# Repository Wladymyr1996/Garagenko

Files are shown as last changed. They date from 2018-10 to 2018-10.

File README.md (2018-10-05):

# Garagenko
Garagenko is a project of remote controller for garage door or gate.<br><br>
You can set youre language in Garagenko.ino, in define option LANG. You must wite code of youre language.<br>
Now you can set next languages:<br>
* Ukrainian     0
* English       1
* Russian       2

Ви можете встановити Вашу мову у файлі Garagenko.ino в LANG встановіть код Вашої мови.<br>
Наразі доступні коди:<br>
* Українська    0
* Англійська    1
* Російська     2

Вы можете использовать Ваш язык в файле Garagenko.ino в LANG утсановите код Вашего языка.<br>
Сейчас доступны коды:
* Украинский    0
* Английский    1
* Русский       2

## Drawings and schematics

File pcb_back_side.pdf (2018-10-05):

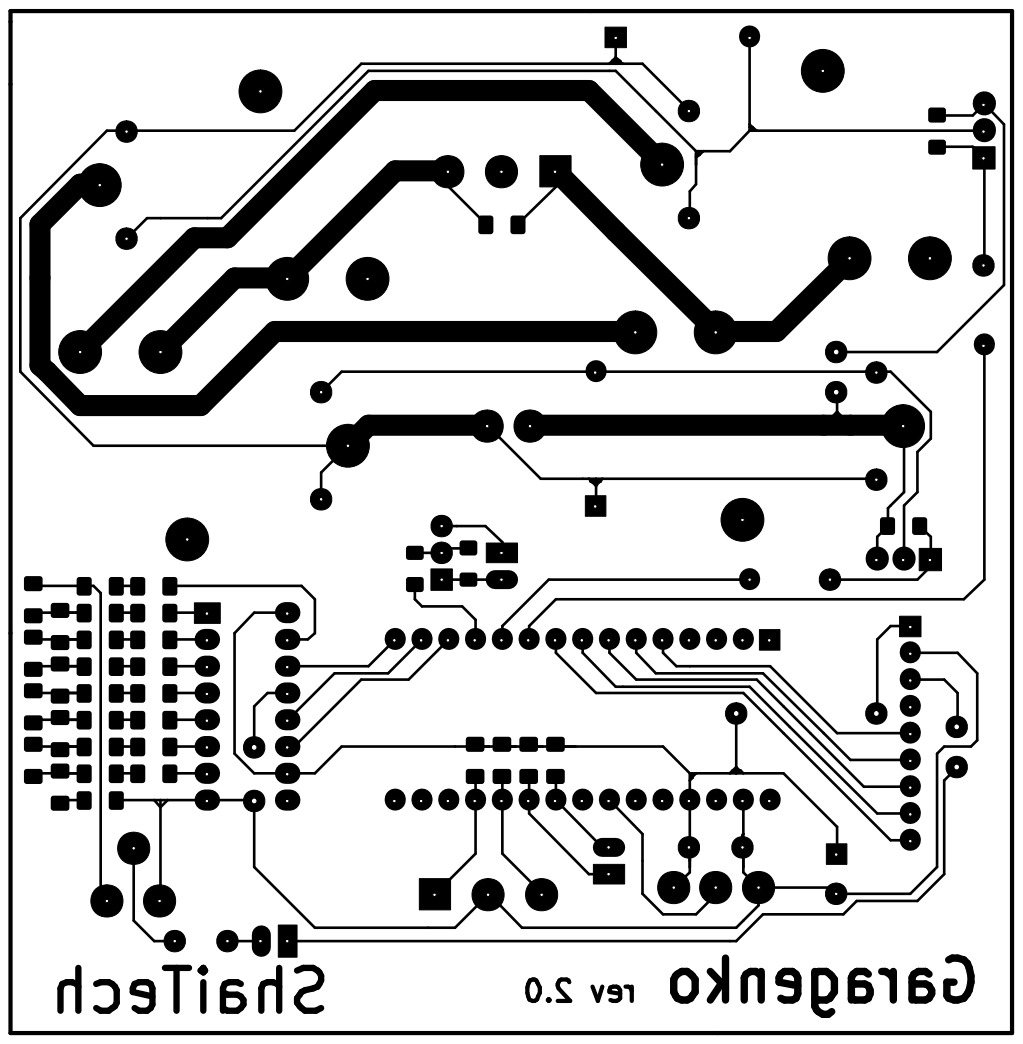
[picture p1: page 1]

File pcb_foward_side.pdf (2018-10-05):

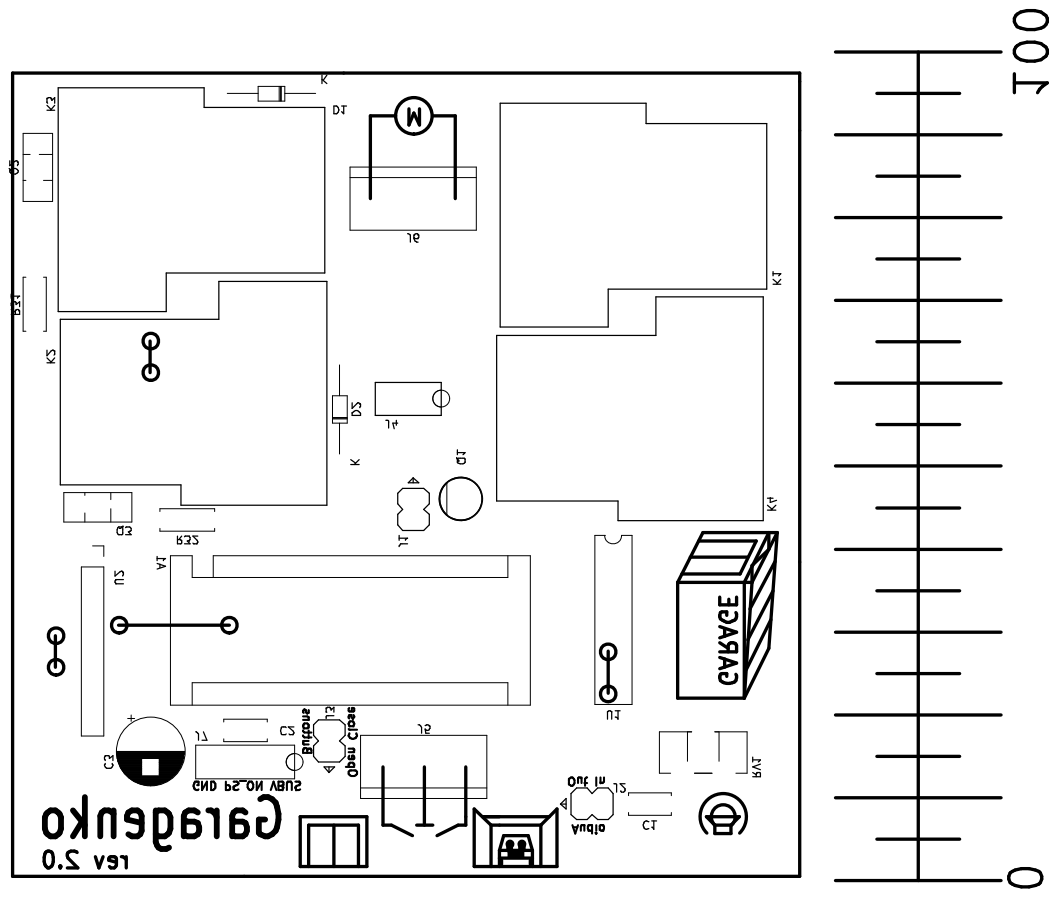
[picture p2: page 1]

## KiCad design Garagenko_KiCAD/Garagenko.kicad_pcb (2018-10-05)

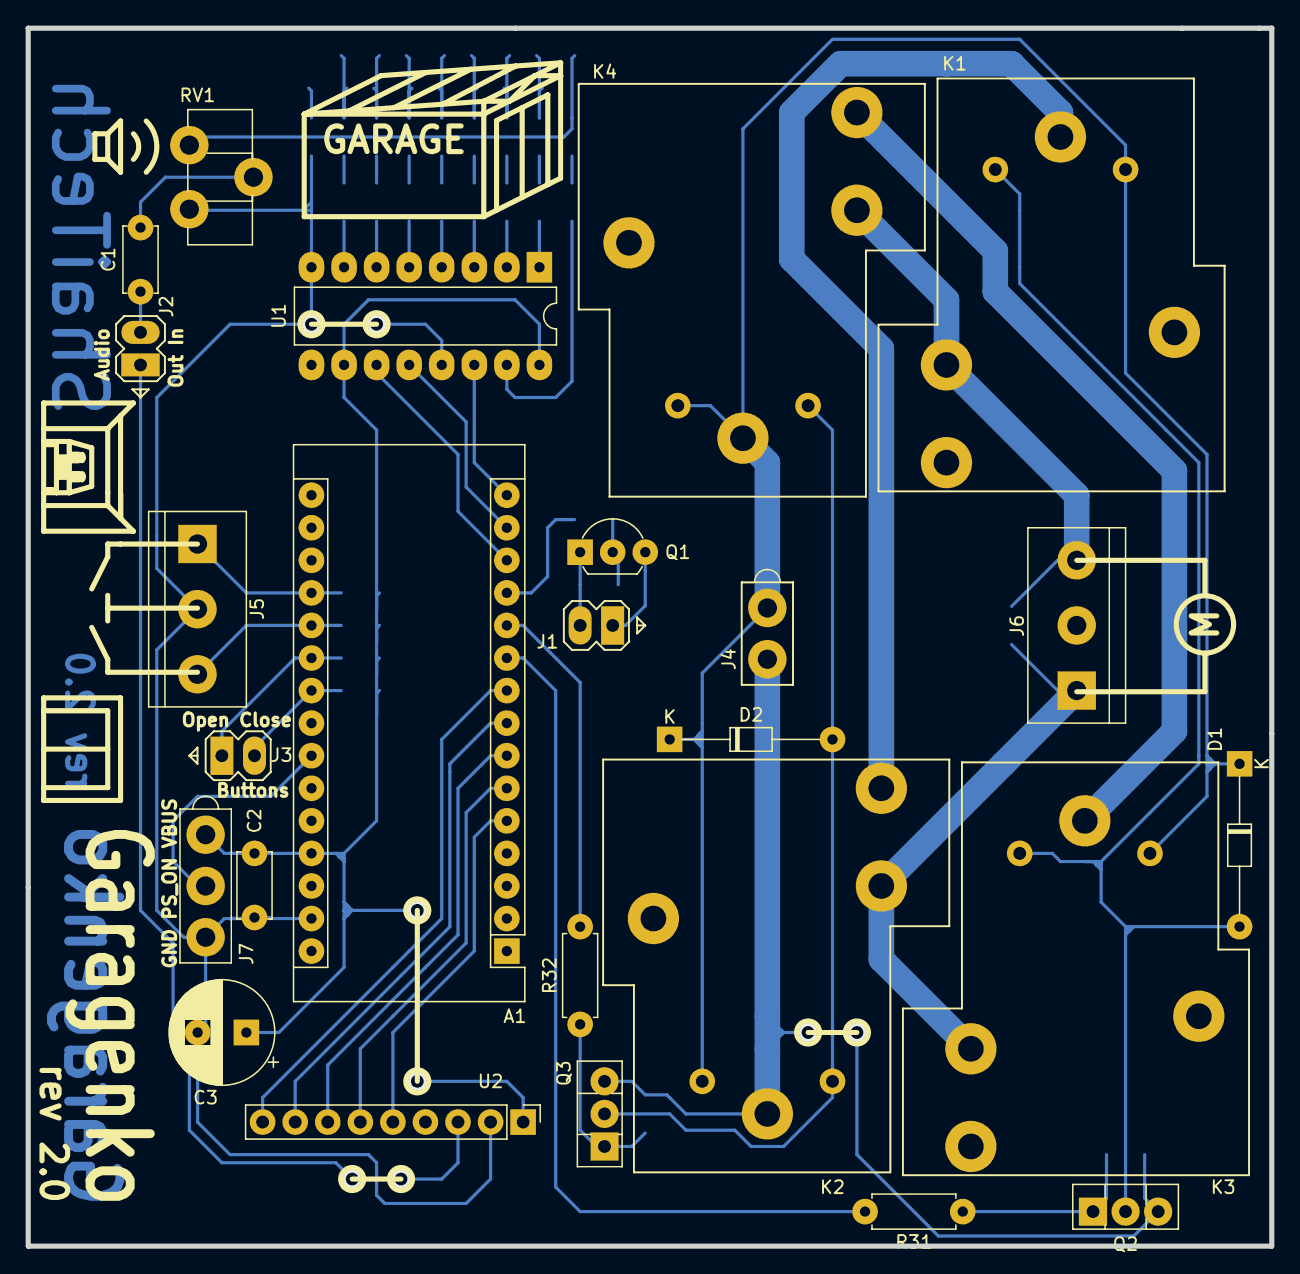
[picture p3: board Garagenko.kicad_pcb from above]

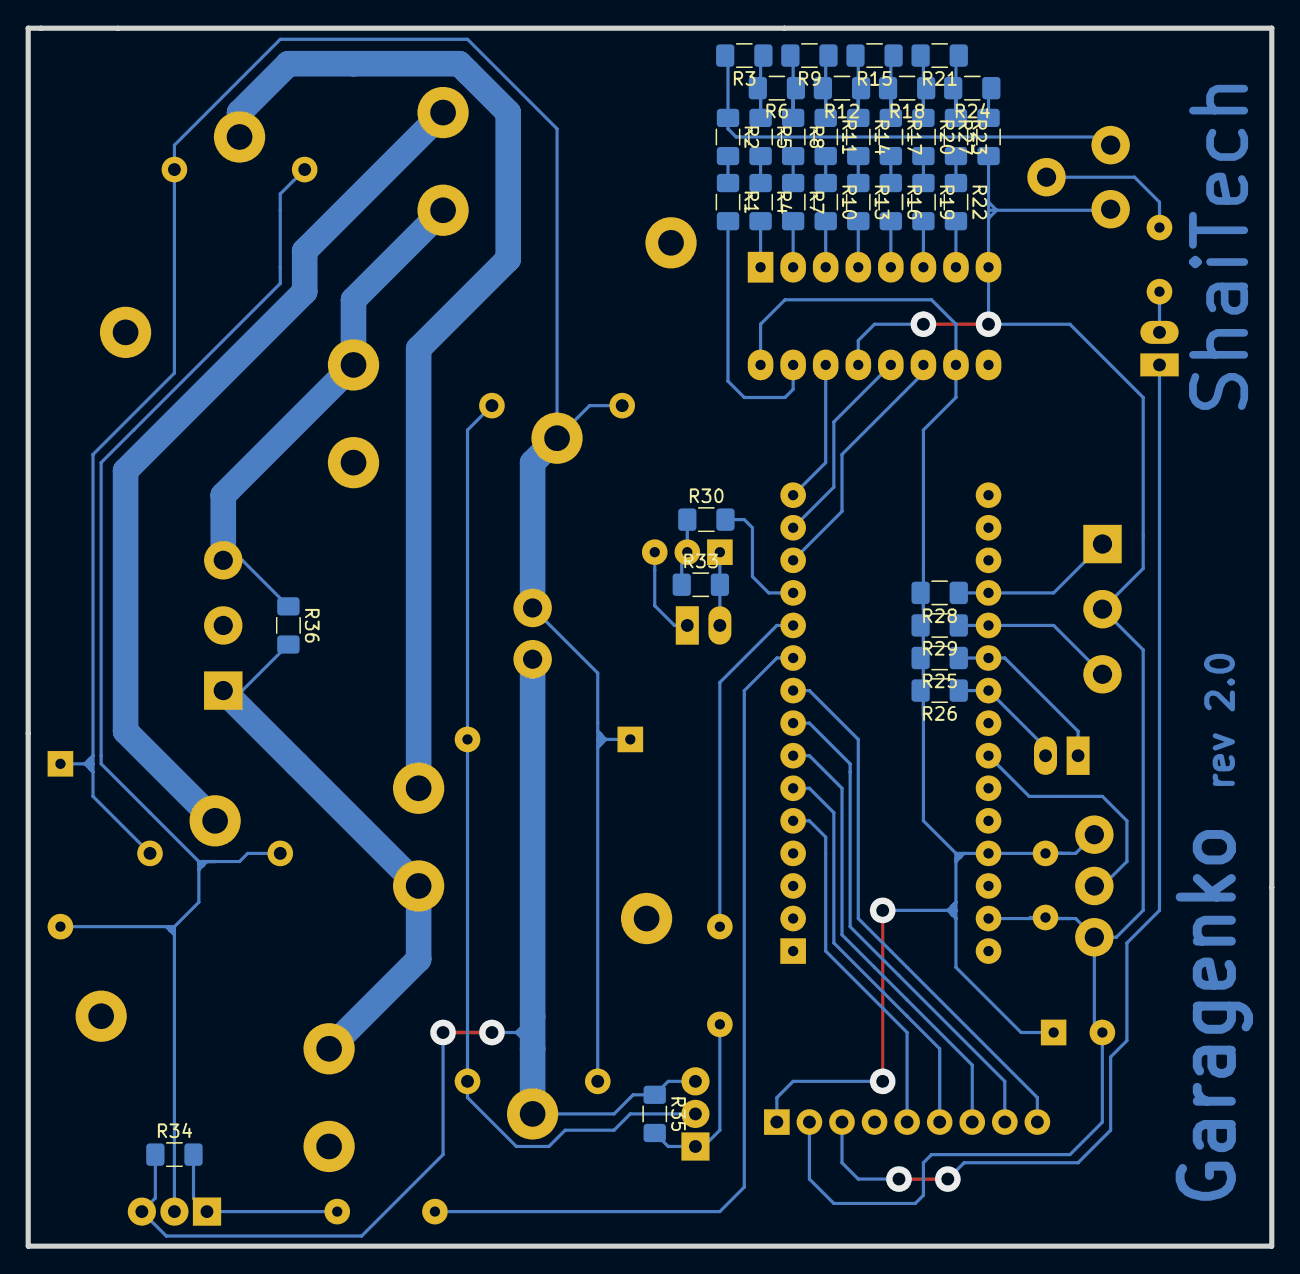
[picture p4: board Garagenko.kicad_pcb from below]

Board: 2 copper layers, 97.0 x 95.0 mm, 59 parts (34 on the bottom side), 59 nets.

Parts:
A1: Arduino_Nano_v3.x; Arduino_Nano
C1, C2: 100nF; C_Disc_D5.0mm_W2.5mm_P5.00mm
C3: 1000uF; CP_Radial_D8.0mm_P3.80mm
D1, D2: 1N4007; D_DO-34_SOD68_P12.70mm_Horizontal
J1: btnCallEnd; Conn_1x2_d1mm
J2: audio; Conn_1x2_d1mm
J3: Buttons; Conn_1x2_d1mm
J4: POWER; Conn_1x2_d1.5mm
J5: Limit Switches; TerminalBlock_bornier-3_P5.08mm
J6: Motor Out; TerminalBlock_bornier-3_P5.08mm
J7: ATX; Conn_1x3_d1.5mm
K1, K2, K3, K4: JQX-15F
Q1: BC547; TO-92L_Inline_Wide
Q2, Q3: BD137; TO-126-3_Vertical
R1, R2, R3, R4, R5, R6, R7, R8, R9, R10, R11, R12, R13, R14, R15, R16, R17, R18, R19, R20, R21, R22, R23, R24, R27, R30, R33, R34, R35, R36: 2.2K; R_1206_3216Metric_Pad1.42x1.75mm_HandSolder
R25, R26, R28, R29: 4.7K; R_1206_3216Metric_Pad1.42x1.75mm_HandSolder
R31, R32: 220R; R_Axial_DIN0207_L6.3mm_D2.5mm_P7.62mm_Horizontal
RV1: 20k; Potentiometer_Piher_PT-10-H05_Horizontal
U1: 74HC595; DIP-16_W7.62mm_LongPads
U2: MT8870_Module; PinHeader_1x09_P2.54mm_Vertical

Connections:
+12V: D1.1, D2.1, J4.1, K1.2, K2.2, K3.2, K4.2, K4.3
AudioOut: C1.1, J2.2
Btn_Close: A1.22, J3.2, R26.1
Btn_Open: A1.21, J3.1, R25.1
DS: A1.15, U1.14
GND: J4.2, K2.3, Q2.3, Q3.3, R34.1, R35.1
GNDD: A1.29, C2.2, C3.2, J5.2, J7.3, R27.1, RV1.3, U1.8, U1.13, U2.2
Limit_Swch_Close: A1.20, J5.3, R29.1
Limit_Swch_Open: A1.19, J5.1, R28.1
M1: J6.1, K2.5, K3.5
M2: J6.3, K1.5, K4.5
M_Close: A1.11, R32.2
M_Open: A1.10, R31.2
unnamed: C1.2, RV1.2
unnamed: D1.2, K1.4, K3.4, Q2.2
unnamed: D2.2, K2.4, K4.4, Q3.2
unnamed: K1.3, K2.6
unnamed: K3.3, K4.6
unnamed: Q1.2, R30.1, R33.1
unnamed: Q2.1, R31.1, R34.2
unnamed: Q3.1, R32.1, R35.2
unnamed: R1.1, R2.2
unnamed: R1.2, U1.15
unnamed: R2.1, R3.2, RV1.1
unnamed: R3.1, R5.1, R6.2
unnamed: R4.1, R5.2
unnamed: R4.2, U1.1
unnamed: R6.1, R8.1, R9.2
unnamed: R7.1, R8.2
unnamed: R7.2, U1.2
unnamed: R10.1, R11.2
unnamed: R10.2, U1.3
unnamed: R9.1, R11.1, R12.2
unnamed: R12.1, R14.1, R15.2
unnamed: R13.1, R14.2
unnamed: R13.2, U1.4
unnamed: R15.1, R17.1, R18.2
unnamed: R16.1, R17.2
unnamed: R16.2, U1.5
unnamed: R18.1, R20.1, R21.2
unnamed: R19.1, R20.2
unnamed: R19.2, U1.6
unnamed: R21.1, R23.1, R24.2
unnamed: R22.1, R23.2
unnamed: R22.2, U1.7
unnamed: R24.1, R27.2
PS_ON: A1.24, J7.2
PhoneAudio: J2.1, U2.3
Q1: A1.9, U2.9
Q2: A1.8, U2.8
Q3: A1.7, U2.7
Q4: A1.6, U2.6
SH_CP: A1.13, U1.11
ST_CP: A1.14, U1.12
StQ: A1.5, U2.5
VBUS: A1.27, C2.1, C3.1, J7.1, R25.2, R26.2, R28.2, R29.2, U1.10, U1.16, U2.1
btnCallEnd: A1.12, R30.2
btnCallEndIn: J1.1, Q1.3
btnCallEndOut: J1.2, Q1.1, R33.2

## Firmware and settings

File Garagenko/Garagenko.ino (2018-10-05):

//////////////////////////////////////////////////////////////////////////
//						Project / Проект: Garagenko						//
//																	  	//
//		  Author / Автор: Stanuk Volodymyr / Стадник Володимир		  	//
//		  	Date / Дата: 3 october 2018 / 3 жовтня 2018				  	//
//																	  	//
////////////////////////////////////////////////////////////////////////// 

/*	This file is part of Garagenko.
 * 
 *
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
 *	(Цей файл — частина Garagenko.
 *
 *	Garagenko - вільна програма: ви можете перерозповсюджувати її і/або
 *	міняи її на умовах Загальної громадської ліцензії GNU у тому вигляді,
 *	в якому вона була опублікована Фондом вільного програмного забезпечення;
 *
 *	Garagenko розповюджується в нажії, що вона буде корисною, але
 *	БЕЗ ВСІЛЯКИХ ГАРАНТІЙ; навіть без неявної гарантії ТОВАРНОГО ВИДУ
 *	або ПРИДАТНОСТІ ДЛЯ ВИЗНАЧЕНИХ ЦІЛЕЙ. Детальніше див. в Загальній
 *	громадській лицензії GNU.

 *	Ви повинні були отримати копію Загальної суспільної ліцензії GNU
 *	разом із цією програмою. Якщо це не так, див.
 *	<https://www.gnu.org/licenses/>.)
*/

//Мова встановлюється за її кодом. Наразі доступні такі мови:
//Language can installed by code. Available languages:
//Language/Мова		|	Code/Код
//Українська		|		0
//English			|		1
//Русский			|		2

#define LANG 0

#define OpenCodeDTMF 1
#define CloseCodeDTMF 2
#define GetStatusDTMF 10

#include <TimerOne.h>
#include "headers/limit_switches.h"
#include "headers/phone.h"
#include "headers/DTMF.h"
#include "headers/door.h"
#include "headers/buttons.h"
#include "headers/audio.h"

TLimitSwitches LimitSwitches;
TPhone Phone;
TDTMF DTMF;
TDoor Door;
TButton Button;
TAudio Audio;

bool CallPhone = false;
bool WaitCallEnd = false;

void sayStatus() {
	if (Door.getStatus() == TDoor::isOpening) {
		Audio.play(TAudio::soundOpening);
		Audio.play(TAudio::soundProcess);
		return;
	}
	if (Door.getStatus() == TDoor::isClosing) {
		Audio.play(TAudio::soundClosing);
		Audio.play(TAudio::soundProcess);
		return;
	}
	if (LimitSwitches.getStatus() == TLimitSwitches::Opened) {
		Audio.play(TAudio::soundOpened);
		return;
	}
	if (LimitSwitches.getStatus() == TLimitSwitches::Closed) {
		Audio.play(TAudio::soundClosed);
		return;
	}
	Audio.play(TAudio::soundStopped);
}

void Open() {
	if ((LimitSwitches.getStatus() != TLimitSwitches::Opened) || 
		(Door.getStatus() == TDoor::isClosing)) Door.doOpen();
	if (CallPhone) {
		if (Door.getStatus() == TDoor::isStoped) sayStatus();
		if (Door.getStatus() == TDoor::isOpening) {
			Audio.play(TAudio::soundOpening);
			Audio.play(TAudio::soundProcess);
		}
	}
}

void Close() {
	if ((LimitSwitches.getStatus() != TLimitSwitches::Closed) || 
		(Door.getStatus() == TDoor::isOpening)) Door.doClose();
	if (CallPhone) {
		if (Door.getStatus() == TDoor::isStoped) sayStatus();
		if (Door.getStatus() == TDoor::isClosing) {
			Audio.play(TAudio::soundClosing);
			Audio.play(TAudio::soundProcess);
		}
	}
}

void Stop() {
	Door.doStop();
	if (CallPhone) {
		sayStatus();
		WaitCallEnd = true;
	}
}

void NewDTMF() {
	uint8_t code = DTMF.getDTMFcode();
	switch (code) {
		case OpenCodeDTMF: CallPhone = true; Open(); break;
		case CloseCodeDTMF: CallPhone = true; Close(); break;
		case GetStatusDTMF: sayStatus(); break;
	}
}

void AudioTimer() {
	Audio.doWork();
}

void setup() {
	Timer1.initialize(220);
	Timer1.attachInterrupt(AudioTimer);
	attachInterrupt(digitalPinToInterrupt(2), NewDTMF, FALLING);
	Serial.begin(9600);
}

void loop() {
	LimitSwitches.doWork();
	Phone.doWork();
	Door.doWork();
	Button.doWork();
	
	if (LimitSwitches.isNewStatus()) {
		if ((LimitSwitches.getStatus() == TLimitSwitches::Opened) && (Door.getStatus() == TDoor::isOpening)) Stop();
		if ((LimitSwitches.getStatus() == TLimitSwitches::Closed) && (Door.getStatus() == TDoor::isClosing)) Stop();
	}
	if (Button.isPressed()) {
		TButton::TPressed tmp = Button.getPressedButton();
		switch (tmp) {
			case TButton::Open: Open(); break;
			case TButton::Close: Close(); break;
		}
	}
	
	if ((WaitCallEnd) && (!Audio.isBusy())) {
		CallPhone = false;
		WaitCallEnd = false;
		Phone.endCall();
	}
	delay(10);
}

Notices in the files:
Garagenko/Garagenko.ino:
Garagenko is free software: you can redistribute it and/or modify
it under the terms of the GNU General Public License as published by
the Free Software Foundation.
